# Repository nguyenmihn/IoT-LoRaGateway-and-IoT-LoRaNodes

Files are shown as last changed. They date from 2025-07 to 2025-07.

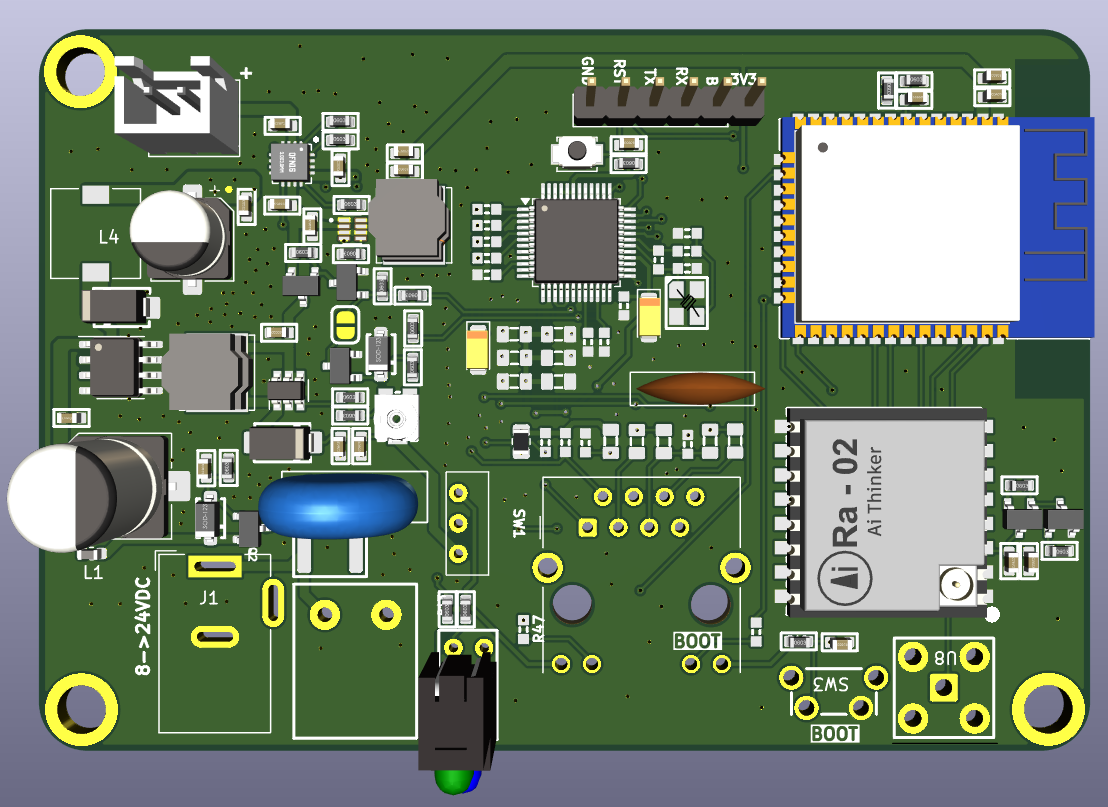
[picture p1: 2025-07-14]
gateway.png

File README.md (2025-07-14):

# IoT-LoRaGateway-and-IoT-LoRaNodes
Design and implementation of IoT-LoRaGateway and IoT-LoRaNodes applied in a building safety monitoring system (sponsored by ICE Meca Tech, Korea &amp; IoTVision)
# 🔥 Panel Safety Monitoring System (PSMS)

**PSMS** is an embedded IoT project integrating hardware design, firmware, and LoRa/TCP-IP communication to monitor and detect fire risks inside electrical panels.

---

## 📌 Project Overview

- **Goal**: Detect early signs of sparks, smoke, and temperature anomalies in panels.
- **Use cases**: Industrial installations like thermal power plants.
- **Communication**: LoRa for remote, low-power detection; TCP-IP as wired fallback.

---

## ⚙️ Features

- IR Spark + UV Spark sensors  
- IR Temperature sensor + 2-channel K-type thermocouples  
- Smoke sensor with high sensitivity  
- Real-time monitoring and alerting via embedded firmware  
- HMI interface for live data reading  
- LoRa range up to 2 km; Ethernet option  
- Battery backup to ensure operation during power failure

---

## 🧩 Hardware Components

- Custom PCB with sensor interfaces  
- MCU (e.g., STM32 or ESP32) running embedded C/C++ firmware  
- LoRa module (e.g., SX126x series) or Ethernet board  
- Enclosure designed for panel mounting

---

## 🗂 Repository Structure (Example)

├── hardware/ # PCB schematics, Gerbers, BOM

├── firmware/ # MCU code (C/C++), sensor drivers, LoRa/TCP‑IP stack

├── gateway/ # LoRa gateway or server-side interface code

└── README.md # This file

yaml
Sao chép
Chỉnh sửa

---

## 🚀 Quick Start

1. **Hardware setup**:  
   Assemble PCB, connect sensors, LoRa/Ethernet, and battery backup.

2. **Build firmware**:  
   ```bash
   cd firmware
   make all
hoặc dùng PlatformIO / STM32CubeIDE.

Configure LoRa:

Set frequency (433MHz)

Configure gateway addresses

Enable TCP-IP if used

Deploy HMI:
Copy firmware/ui files lên HMI panel.

Test & Calibrate:
Verify readings, range test LoRa, simulate spark/smoke.

✅ Deployed Example
Installed in Yeongheung Thermal Power Plant (Unit #5, 870 MW)

Runs under KOEN-supported R&D project (Dec 2022–Dec 2024)

🛠 Tech Stack
MCU: STM32/ESP32 with firmware in C/C++

Communication: LoRa (Semtech SX126x), TCP/IP Ethernet module

Sensors: IR/UV spark, temperature, thermocouple, smoke

Build tools: Makefile or PlatformIO / STM32CubeIDE

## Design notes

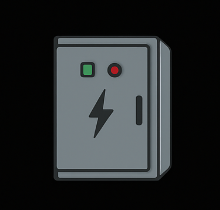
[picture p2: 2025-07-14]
firmware/web/tudien.png

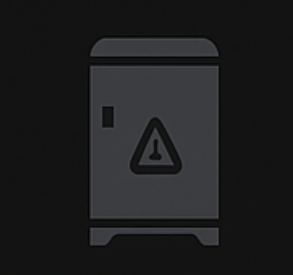
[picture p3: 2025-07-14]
firmware/web/screenshot_1748689128.png

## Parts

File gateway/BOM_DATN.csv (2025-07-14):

# | Reference | Value | Datasheet | Footprint | Qty | DNP
1 | BT1 | Battery_18650 | ~ | IVS_FOOTPRINTS:XH 2.54 2Pin Female | 1
2 | C1,C9,C10,C11,C12,C16,C18 | 10uF | ~ | IVS_FOOTPRINTS:C_0603 | 7 | https://www.thegioiic.com/tu-gom-0603-10uf-25v
3 | C2,C13,C17,C19,C23 | 100nF | ~ | IVS_FOOTPRINTS:C_0603 | 5 | https://www.thegioiic.com/tu-gom-0603-100nf-0-1uf-50v
4 | C3,C4,C6,C7,C8,C15,C21 | 1uF | ~ | IVS_FOOTPRINTS:C_0603 | 7 | https://www.thegioiic.com/tu-gom-0603-1uf-50v
5 | C5 | 220uF 35V | ~ | Capacitor_SMD:CP_Elec_8x10.5 | 1 | https://www.thegioiic.com/tu-nhom-smd-220uf-35v-8x10-5mm
6 | C14 | 110uF 10V | ~ | Capacitor_SMD:CP_Elec_6.3x5.4 | 1 | https://www.thegioiic.com/tu-nhom-smd-330uf-6-3v-6-3x7-7mm
7 | C29,C30 | 18p | ~ | IVS_FOOTPRINTS:C_0603 | 2 | https://www.thegioiic.com/tu-gom-0603-18pf-50v
8 | C31,C45,C46,C47,C48,C49,C50 | 0.1uF | ~ | -- mixed values -- | 7
9 | C33 | 1nF/2kV | ~ | Capacitor_THT:C_Disc_D10.0mm_W2.5mm_P5.00mm | 1
10 | C34 | 22nF | ~ | IVS_FOOTPRINTS:C_0603 | 1 | https://www.thegioiic.com/tu-gom-0603-22nf-50v
11 | C35,C38 | 6.8nF | ~ | IVS_FOOTPRINTS:C_0805 | 2 | https://www.thegioiic.com/tu-gom-0805-6-8nf-50v
12 | C39,C40 | 10nF | ~ | IVS_FOOTPRINTS:C_0603 | 2 | https://www.thegioiic.com/tu-gom-0603-10nf-50v
13 | C41 | 4.7uF | ~ | IVS_FOOTPRINTS:C_0603 | 1
14 | C51,C52 | 10 uF 16V | ~ | Capacitor_Tantalum_SMD:CP_EIA-3216-10_Kemet-I | 2
15 | D1 | LED_Dual_AKAK | ~ | IVS_FOOTPRINTS:LED_Housing_Dual | 1 | https://www.thegioiic.com/bo-chi-thi-2-led-xanh-la-do-3mm-de-nhua-han-pcb
16 | D2,D3 | SS34 |  | IVS_FOOTPRINTS:D_SMA | 2 | https://www.thegioiic.com/twgmc-ss34-sma-diode-schottky-3a
17 | F1 | 1A | ~ | IVS_FOOTPRINTS:F_1812 | 1 | https://www.thegioiic.com/mf-msmf020-2-cau-chi-tu-phuc-hoi-1812-0-20a-30v
18 | FB1 | FerriteBead | ~ | IVS_FOOTPRINTS:R_0805_2012Metric | 1
19 | H1 | MountingHole | ~ | minh_iot:MountingHole_3mm_M4_DIN965_Pad | 1
20 | J1 | Jack-DC | ~ | Connector_BarrelJack:BarrelJack_Wuerth_6941xx301002 | 1 | https://www.thegioiic.com/dc5521-dau-noi-nguon-dc-cai-5521-han-pcb-kim-2-1mm
21 | J2 | Screw_Terminal_01x02 | ~ | IVS_FOOTPRINTS:KF-5.08-2P | 1
22 | J3 | Conn_01x06_Male | ~ | Connector_PinHeader_2.54mm:PinHeader_1x06_P2.54mm_Vertical | 1
23 | J6 | RJ45_Hanrun_HR911105A_Horizontal | https://datasheet.lcsc.com/lcsc/1811141815_HANRUN-Zhongshan-HanRun-Elec-HR911105A_C12074.pdf | Connector_RJ:RJ45_Hanrun_HR911105A_Horizontal | 1
24 | JP1 | SolderJumper_2_Open | ~ | IVS_FOOTPRINTS:SolderJumper-2_P1.3mm_Open_RoundedPad1.0x1.5mm | 1
25 | L1 | VHF160808H2N2ST | ~ | Inductor_SMD:L_0603_1608Metric | 1 | https://www.thegioiic.com/vhf160808h2n2st-cuon-cam-2-2nh-0603-1a
26 | L2 | 22uH | ~ | Inductor_SMD:L_Bourns_SRN6045TA | 1 | https://www.thegioiic.com/cuon-cam-dan-smd-cd53-5852-220-22uh-1-5a
27 | L3 | 2.2uH | ~ | Inductor_SMD:L_Bourns_SRN6045TA | 1
28 | L4 | 47uH | ~ | IVS_FOOTPRINTS:L_7.3x7.3_H4.5 | 1 | https://www.thegioiic.com/cuon-cam-dan-smd-cdrh74-7345-470-47uh-1-03a
29 | Q1,Q3,Q5 | SI2300 | -- mixed values -- | IVS_FOOTPRINTS:SOT23-3 | 3 | https://www.thegioiic.com/si2300ds-mosfet-kenh-n-30v-3-6a-sot-23
30 | Q2,Q4,Q6 | SI2301 | -- mixed values -- | IVS_FOOTPRINTS:SOT23-3 | 3 | https://www.thegioiic.com/si2301ds-mosfet-kenh-p-20v-2-3a-sot-23-3
31 | R1,R6,R13,R14 | 1K | ~ | IVS_FOOTPRINTS:R_0603 | 4
32 | R2,R12,R17,R18 | 10K | ~ | IVS_FOOTPRINTS:R_0603 | 4
33 | R3 | 12k | ~ | IVS_FOOTPRINTS:R_0603 | 1
34 | R4 | 270K | ~ | IVS_FOOTPRINTS:R_0603 | 1
35 | R5,R9 | 1K2 | ~ | IVS_FOOTPRINTS:R_0603 | 2
36 | R7,R11,R23,RV2 | 100K | ~ | -- mixed values -- | 4
37 | R8,R15,R24 | 20K | ~ | IVS_FOOTPRINTS:R_0603 | 3
38 | R10 | 220K | ~ | IVS_FOOTPRINTS:R_0603 | 1
39 | R16 | 2K7 | ~ | IVS_FOOTPRINTS:R_0603 | 1
40 | R36 | 1M | ~ | IVS_FOOTPRINTS:R_0603 | 1
41 | R37,R38,R45,R52,R53 | 0R | ~ | IVS_FOOTPRINTS:R_0603 | 5
42 | R46,R47 | 330R | ~ | IVS_FOOTPRINTS:R_0603 | 2
43 | R48,R50 | 49R9 | ~ | IVS_FOOTPRINTS:R_0603 | 2
44 | R51 | 10R | ~ | IVS_FOOTPRINTS:R_0805 | 1
45 | R54,R55 | 82R 1% | ~ | IVS_FOOTPRINTS:R_0805 | 2
46 | R56 | 12.4k | ~ | IVS_FOOTPRINTS:R_0603 | 1
47 | RV1 | 07D330K | ~ | Varistor:RV_Disc_D12mm_W4.2mm_P7.5mm | 1 | https://www.thegioiic.com/tu-chong-set-varistor-07d330k-33v
48 | SW1 | MSK-38/SS-12D00 | https://www.nidec-components.com/e/catalog/switch/cas.pdf | IVS_FOOTPRINTS:SW_MSK-38 | 1
49 | SW2,SW3 | SW_Push | ~ | -- mixed values -- | 2
50 | TP1 | TestPoint | ~ | IVS_FOOTPRINTS:TestPoint_Pad_D1.0mm | 1
51 | U1 | TPS62840DLCR |  | IVS_FOOTPRINTS:VSON-HR - 1 mm | 1
52 | U2 | BQ24075RGT | http://www.ti.com/lit/ds/symlink/bq24075.pdf | IVS_FOOTPRINTS:VQFN-16-1EP_3x3mm_P0.5mm_EP1.6x1.6mm_ThermalVias | 1
53 | U3 | MT3608 | https://www.olimex.com/Products/Breadboarding/BB-PWR-3608/resources/MT3608.pdf | IVS_FOOTPRINTS:SOT-23-6 | 1 | https://www.thegioiic.com/mt3608-ic-dieu-chinh-tang-ap-2a-sot-23-6
54 | U4 | XL1509 | https://datasheet.lcsc.com/lcsc/1809050422_XLSEMI-XL1509-5-0E1_C61063.pdf | IVS_FOOTPRINTS:SOIC-8_3.9x4.9mm_P1.27mm | 1 | https://www.thegioiic.com/xl1509-5-0e1-ic-on-ap-5v-2a-8-soic
55 | U5 | ESP32-WROOM-32UE | https://www.espressif.com/sites/default/files/documentation/esp32-wroom-32d_esp32-wroom-32u_datasheet_en.pdf | IVS_FOOTPRINTS:ESP32-WROOM-32E | 1 | https://www.thegioiic.com/esp32-wroom-32e-n4-module-wifi-bluetooth-4mb-flash-2-4ghz
56 | U7 | Ai-Thinker-Ra-02 | http://wiki.ai-thinker.com/_media/lora/docs/c048ps01a1_ra-02_product_specification_v1.1.pdf | IVS_FOOTPRINTS:MODULE_RA-02_LORA | 1 | https://www.thegioiic.com/sx1278-lora-ra-02-ai-thinker-mach-thu-phat-rf-433mhz-10km
57 | U8 | Ipex | https://datasheet.lcsc.com/lcsc/1811091710_HRS-Hirose-U-FL-R-SMT-1-80_C88374.pdf | IVS_FOOTPRINTS:Connector_Coaxial_SMA | 1 | https://www.thegioiic.com/ahcg-204-cong-rf-ipex-g1-2-chan-dan-smd
58 | U12 | W5500 | http://wizwiki.net/wiki/lib/exe/fetch.php/products:w5500:w5500_ds_v109e.pdf | Package_QFP:LQFP-48_7x7mm_P0.5mm | 1
59 | Y1 | Crystal_MCU | https://docs.rs-online.com/ec34/0900766b816028ea.pdf | IVS_FOOTPRINTS:Crystal_3225_4P_3.2x2.6mm | 1
60 | Z1 | 3V3 |  | IVS_FOOTPRINTS:D_SOD-123 | 1 | https://www.thegioiic.com/bzt52c5v1-diode-zener-5-1v-500mw
61 | Z2 | 12V |  | IVS_FOOTPRINTS:D_SOD-123 | 1

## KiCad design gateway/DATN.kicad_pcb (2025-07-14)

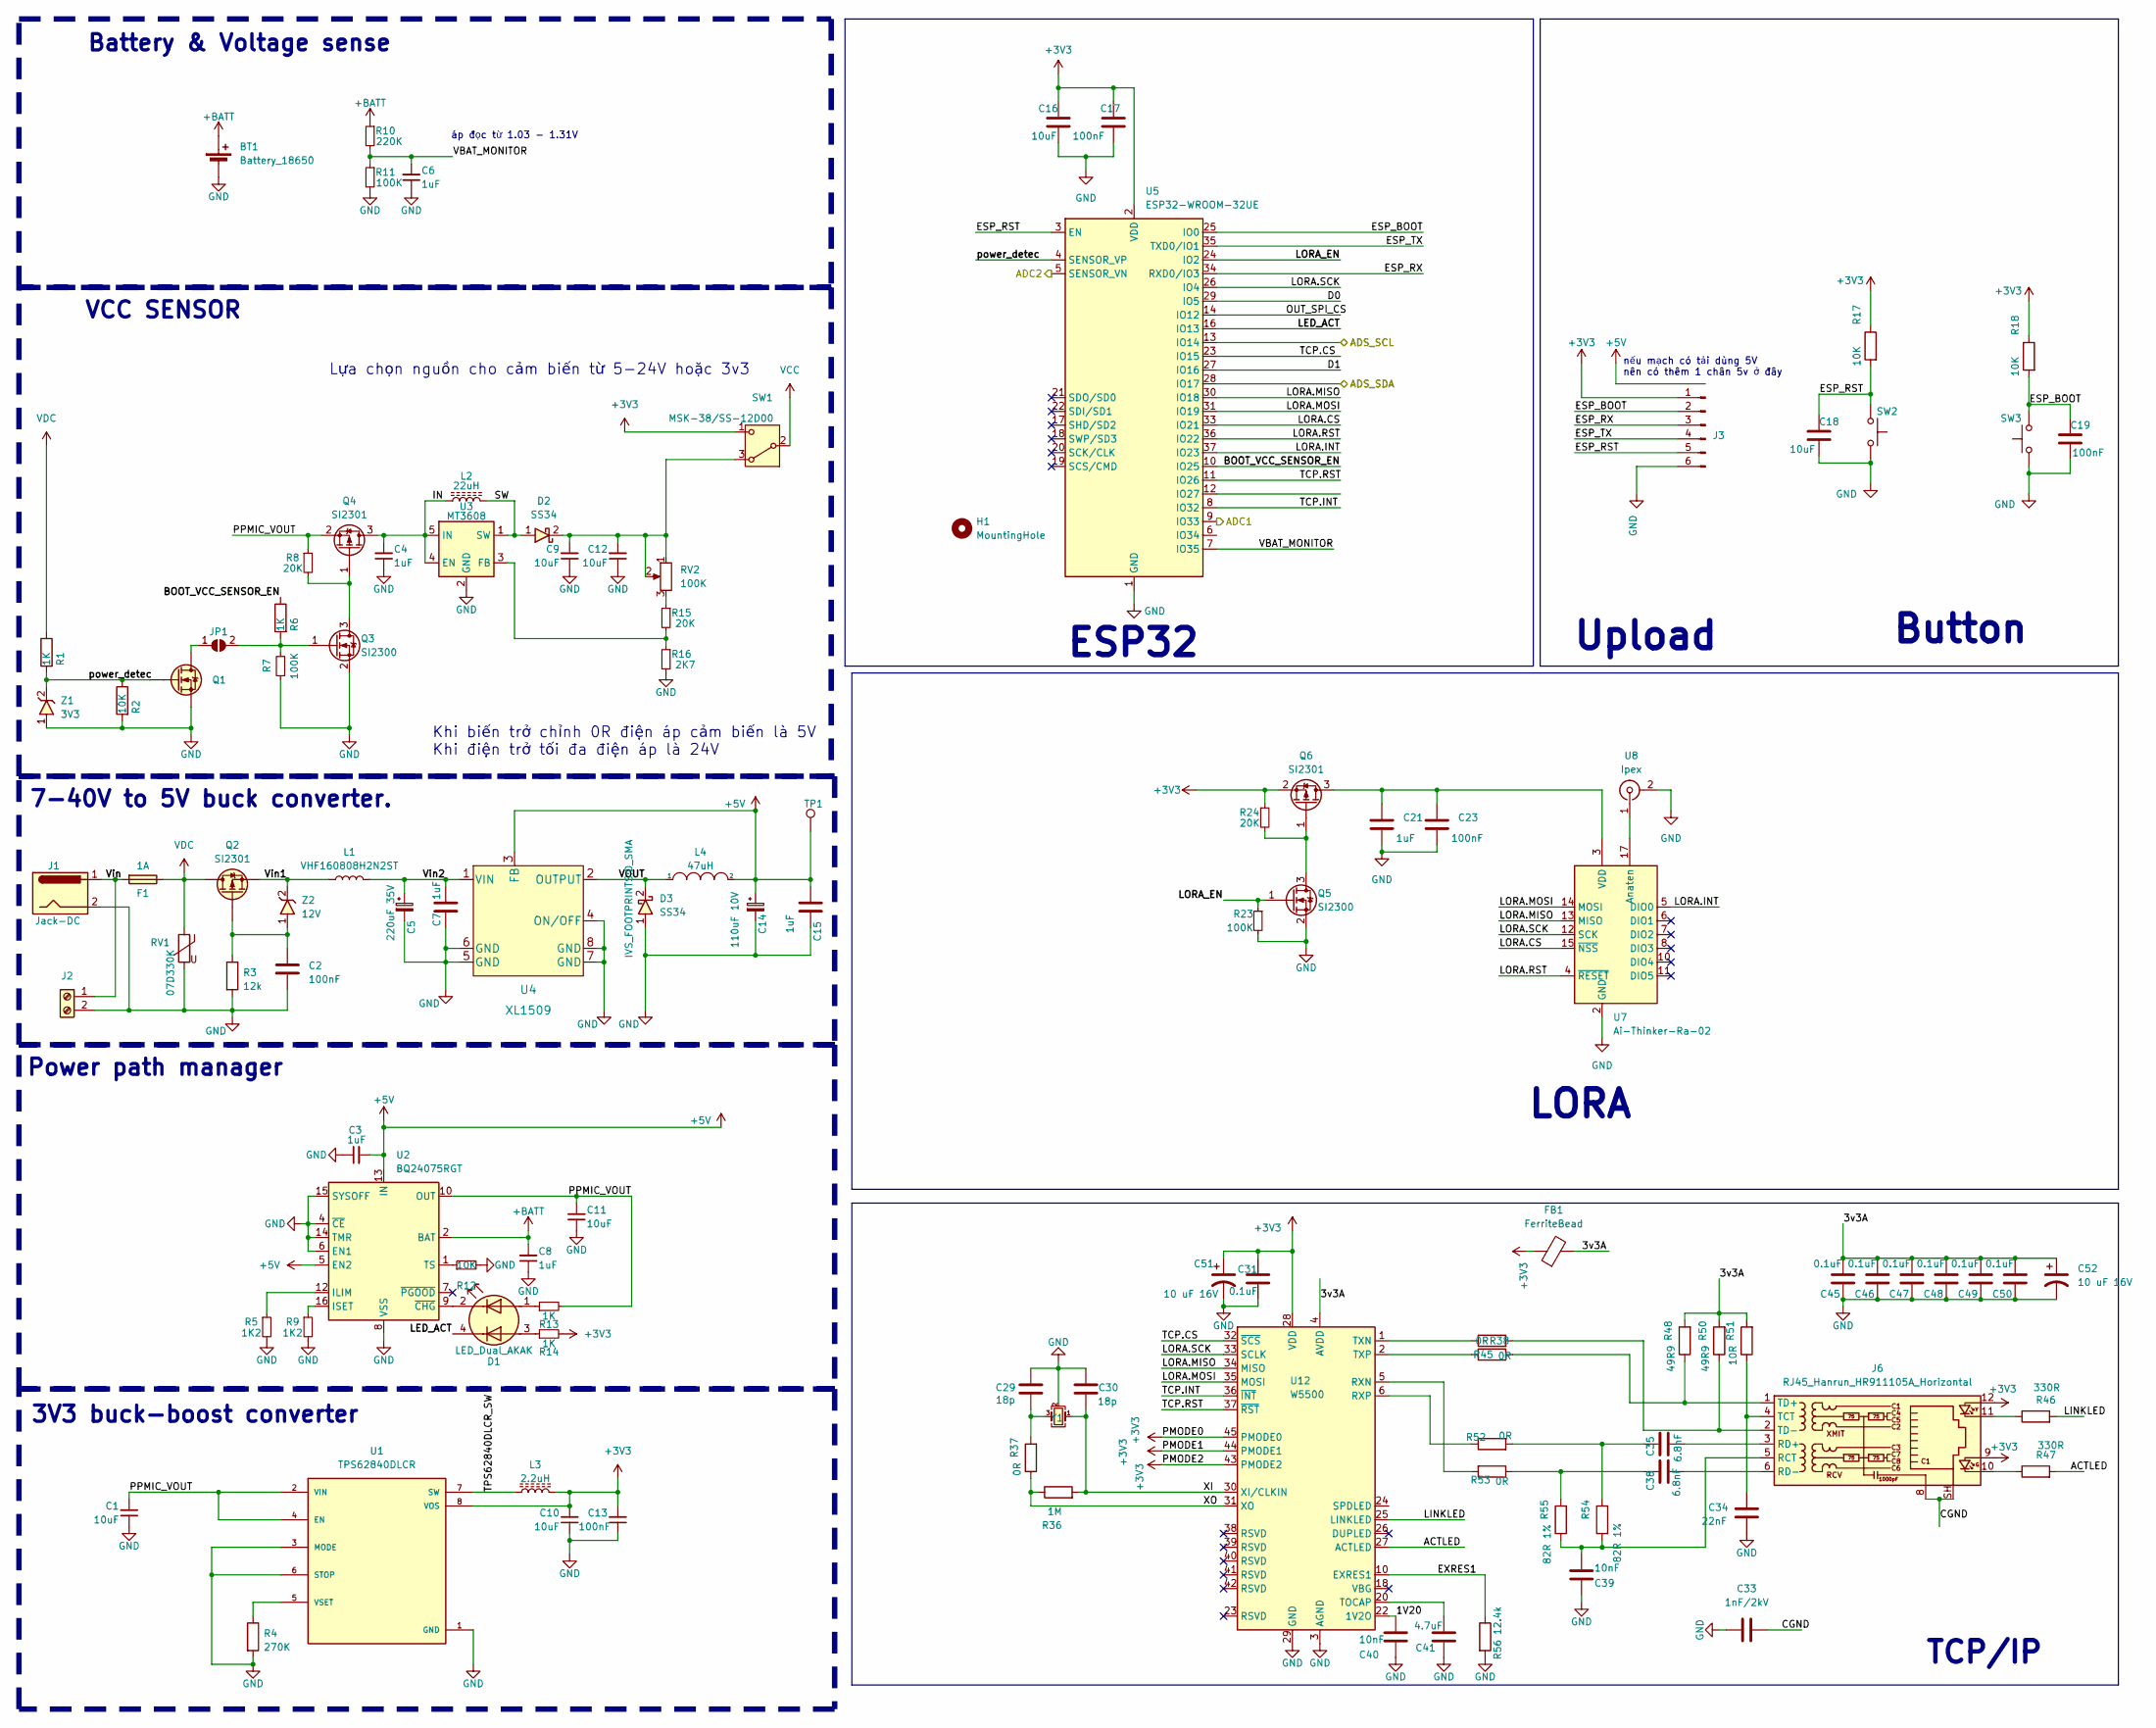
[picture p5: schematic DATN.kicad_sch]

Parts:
BT1: Battery_18650; XH 2.54 2Pin Female
C1, C9, C10, C11, C12, C16, C18: 10uF; C_0603
C2, C13, C17, C19, C23: 100nF; C_0603
C3, C4, C6, C7, C8, C15, C21: 1uF; C_0603
C5: 220uF 35V; CP_Elec_8x10.5
C14: 110uF 10V; CP_Elec_6.3x5.4
C29, C30: 18p; C_0603
C31: 0.1uF; C_0603
C33: 1nF/2kV; C_Disc_D10.0mm_W2.5mm_P5.00mm
C34: 22nF; C_0603
C35, C38: 6.8nF; C_0805
C39, C40: 10nF; C_0603
C41: 4.7uF; C_0603
C45, C46, C47, C48, C49, C50: 0.1uF; C_0805
C51, C52: 10 uF 16V; CP_EIA-3216-10_Kemet-I
D1: LED_Dual_AKAK; LED_Housing_Dual
D2, D3: SS34; D_SMA
F1: 1A; F_1812
FB1: FerriteBead; R_0805_2012Metric
H1: MountingHole; MountingHole_3mm_M4_DIN965_Pad
J1: Jack-DC; BarrelJack_Wuerth_6941xx301002
J2: Screw_Terminal_01x02; KF-5.08-2P
J3: Conn_01x06_Male; PinHeader_1x06_P2.54mm_Vertical
J6: RJ45_Hanrun_HR911105A_Horizontal
JP1: SolderJumper_2_Open; SolderJumper-2_P1.3mm_Open_RoundedPad1.0x1.5mm
L1: VHF160808H2N2ST; L_0603_1608Metric
L2: 22uH; L_Bourns_SRN6045TA
L3: 2.2uH; L_Bourns_SRN6045TA
L4: 47uH; L_7.3x7.3_H4.5
Q1, Q3, Q5: SI2300; SOT23-3
Q2, Q4, Q6: SI2301; SOT23-3
R1, R6, R13, R14: 1K; R_0603
R2, R12, R17, R18: 10K; R_0603
R3: 12k; R_0603
R4: 270K; R_0603
R5, R9: 1K2; R_0603
R7, R11, R23: 100K; R_0603
R8, R15, R24: 20K; R_0603
R10: 220K; R_0603
R16: 2K7; R_0603
R36: 1M; R_0603
R37, R38, R45, R52, R53: 0R; R_0603
R46, R47: 330R; R_0603
R48, R50: 49R9; R_0603
R51: 10R; R_0805
R54, R55: 82R 1%; R_0805
R56: 12.4k; R_0603
RV1: 07D330K; RV_Disc_D12mm_W4.2mm_P7.5mm
RV2: 100K; Potentiometer_Bourns_TC33X_Vertical
SW1: MSK-38/SS-12D00; SW_MSK-38
SW2: SW_Push; SW_SPST_B3U-1000P
SW3: SW_Push; SW_6x6_90DEG
TP1: TestPoint; TestPoint_Pad_D1.0mm
U1: TPS62840DLCR; VSON-HR - 1 mm
U2: BQ24075RGT; VQFN-16-1EP_3x3mm_P0.5mm_EP1.6x1.6mm_ThermalVias
U3: MT3608; SOT-23-6
U4: XL1509; SOIC-8_3.9x4.9mm_P1.27mm
U5: ESP32-WROOM-32UE; ESP32-WROOM-32E
U7: Ai-Thinker-Ra-02; MODULE_RA-02_LORA
U8: Ipex; Connector_Coaxial_SMA
U12: W5500; LQFP-48_7x7mm_P0.5mm
Y1: Crystal_MCU; Crystal_3225_4P_3.2x2.6mm
Z1: 3V3; D_SOD-123
Z2: 12V; D_SOD-123

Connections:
+3V3: C10.2, C13.2, C16.1, C17.1, C31.1, C51.1, FB1.1, J3.1, J6.9, J6.12, L3.2, Q6.2 (S), R14.2, R17.1, R18.1, R24.1, SW1.1 (C), U1.8 (VOS), U5.2 (VDD), U12.28 (VDD), U12.43 (PMODE2), U12.44 (PMODE1), U12.45 (PMODE0)
+5V: C3.2, C14.1, C15.2, L4.2, TP1.1, U2.5 (EN2), U2.13 (IN), U4.3 (FB)
+BATT: BT1.1 (+), C8.2, R10.1, U2.2 (BAT), U2.3 (BAT)
/1V20: C40.2, U12.22 (1V2O)
/3v3A: C45.2, C46.2, C47.2, C48.2, C49.2, C50.2, C52.1, FB1.2, R48.2, R50.2, R51.2, U12.4 (AVDD), U12.8 (AVDD), U12.11 (AVDD), U12.15 (AVDD), U12.17 (AVDD), U12.21 (AVDD)
/ACTLED: R47.2, U12.27 (ACTLED)
/ADC1: U5.9 (IO33)
/ADC2: U5.5 (SENSOR_VN)
/ADS_SCL: U5.13 (IO14)
/ADS_SDA: U5.28 (IO17)
/BOOT_VCC_SENSOR_EN: R6.1, U5.10 (IO25)
/CGND: C33.2, J6.8, J6.SH
/D0: U5.29 (IO5)
/D1: U5.27 (IO16)
/ESP_BOOT: C19.1, J3.2, R18.2, SW3.2, U5.25 (IO0)
/ESP_RST: C18.1, J3.5, R17.2, SW2.2, U5.3 (EN)
/ESP_RX: J3.3, U5.34 (RXD0/IO3)
/ESP_TX: J3.4, U5.35 (TXD0/IO1)
/EXRES1: R56.1, U12.10 (EXRES1)
/IN: C4.2, L2.1, Q4.3 (D), U3.4 (EN), U3.5 (IN)
/LED_ACT: D1.4 (K2), U5.16 (IO13)
/LINKLED: R46.2, U12.25 (LINKLED)
/LORA.CS: U5.33 (IO21), U7.15 (~NSS)
/LORA.INT: U5.37 (IO23), U7.5 (DIO0)
/LORA.MISO: U5.30 (IO18), U7.13 (MISO), U12.34 (MISO)
/LORA.MOSI: U5.31 (IO19), U7.14 (MOSI), U12.35 (MOSI)
/LORA.RST: U5.36 (IO22), U7.4 (~RESET)
/LORA.SCK: U5.26 (IO4), U7.12 (SCK), U12.33 (SCLK)
/LORA_EN: Q5.1 (G), R23.1, U5.24 (IO2)
/OUT_SPI_CS: U5.14 (IO12)
/PPMIC_VOUT: C1.2, C11.2, Q4.2 (S), R8.1, R13.2, U1.2 (VIN), U1.4 (EN), U2.10 (OUT), U2.11 (OUT)
/SW: D2.1, L2.2, U3.1 (SW)
/TCP.CS: U5.23 (IO15), U12.32 (~SCS)
/TCP.INT: U5.8 (IO32), U12.36 (~INT)
/TCP.RST: U5.11 (IO26), U12.37 (~RST)
/TPS62840DLCR_SW: L3.1, U1.7 (SW)
/VBAT_MONITOR: C6.2, R10.2, R11.1, U5.7 (IO35)
/VOUT: D3.2, L4.1, U4.2 (OUTPUT)
/Vin: F1.1, J1.1, J2.1
/Vin1: L1.1, Q2.2 (S), Z2.2
/Vin2: C5.1, C7.2, L1.2, U4.1 (VIN)
/XI: C30.2, R36.2, U12.30 (XI/CLKIN), Y1.1
/XO: R36.1, R37.1, U12.31 (XO)
/power_detec: Q1.1 (G), R1.2, R2.1, U5.4 (SENSOR_VP), Z1.2
GND: BT1.2 (-), C1.1, C2.2, C3.1, C4.1, C5.2, C6.1, C7.1, C8.1, C9.1, C10.1, C11.1, C12.1, C13.1, C14.2, C15.1, C16.2, C17.2, C18.2, C19.2, C21.2, C23.2, C29.1, C30.1, C31.2, C33.1, C34.2, C39.1, C40.1, C41.1, C45.1, C46.1, C47.1, C48.1, C49.1, C50.1, C51.2, C52.2, D3.1, J1.2, J2.2, J3.6, Q1.2 (S), Q3.2 (S), Q5.2 (S), R2.2, R3.2, R4.2, R5.2, R7.2, R9.2, R11.2, R12.2, R16.2, R23.2, R56.2, RV1.2, SW2.1, SW3.1, U1.1 (GND), U1.3 (MODE), U1.6 (STOP), U2.4 (~CE), U2.6 (EN1), U2.8 (VSS), U2.14 (TMR), U2.15 (SYSOFF), U2.17 (VSS), U3.2 (GND), U4.4 (ON/OFF), U4.5 (GND), U4.6 (GND), U4.7 (GND), U4.8 (GND), U5.1 (GND), U5.15 (GND), U5.38 (GND), U5.39 (GND), U7.1 (GND), U7.2 (GND), U7.9 (GND), U7.16 (GND), U8.2, U12.3 (AGND), U12.9 (AGND), U12.14 (AGND), U12.16 (AGND), U12.19 (AGND), U12.29 (GND), U12.48 (AGND), Y1.2, Y1.4, Z1.1
unnamed: C29.2, R37.2, Y1.3
unnamed: C35.1, R52.2, R54.2
unnamed: C38.1, R53.1, R55.2
unnamed: D1.1 (A1), R13.1
unnamed: D1.3 (A2), R14.1
unnamed: D1.2 (K1), U2.9 (~CHG)
unnamed: J6.10, R47.1
unnamed: J6.11, R46.1
unnamed: C39.2, J6.5 (RCT), R54.1, R55.1
unnamed: C35.2, J6.3 (RD+)
unnamed: C38.2, J6.6 (RD-)
unnamed: C34.1, J6.4 (TCT), R51.1
unnamed: J6.1 (TD+), R45.1, R48.1
unnamed: J6.2 (TD-), R38.2, R50.1
unnamed: JP1.1 (A), Q1.3 (D)
unnamed: JP1.2 (B), Q3.1 (G), R6.2, R7.1
unnamed: C2.1, Q2.1 (G), R3.1, Z2.1
unnamed: Q3.3 (D), Q4.1 (G), R8.2
unnamed: Q5.3 (D), Q6.1 (G), R24.2
unnamed: C21.1, C23.1, Q6.3 (D), U7.3 (VDD)
unnamed: R15.1, RV2.3
unnamed: C9.2, C12.2, D2.2, RV2.1, RV2.2, SW1.3 (A)
unnamed: R4.1, U1.5 (VSET)
unnamed: R5.1, U2.12 (ILIM)
unnamed: R9.1, U2.16 (ISET)
unnamed: R12.1, U2.1 (TS)
unnamed: R15.2, R16.1, U3.3 (FB)
unnamed: U7.17 (Anaten), U8.1
unnamed: R53.2, U12.5 (RXN)
unnamed: R52.1, U12.6 (RXP)
unnamed: C41.2, U12.20 (TOCAP)
unnamed: R38.1, U12.1 (TXN)
unnamed: R45.2, U12.2 (TXP)
VCC: SW1.2 (B)
VDC: F1.2, Q2.3 (D), R1.1, RV1.1

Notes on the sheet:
VCC SENSOR
LORA
Lựa chọn nguồn cho cảm biến từ 5-24V hoặc 3v3
3V3 buck-boost converter
Khi biến trở chỉnh 0R điện áp cảm biến là 5V Khi điện trở tối đa điện áp là 24V
nếu mạch có tải dùng 5V nên có thêm 1 chân 5v ở đây
áp đọc từ 1.03 - 1.31V
Button
Upload
Power path manager
ESP32
TCP/IP
7-40V to 5V buck converter.
Battery & Voltage sense

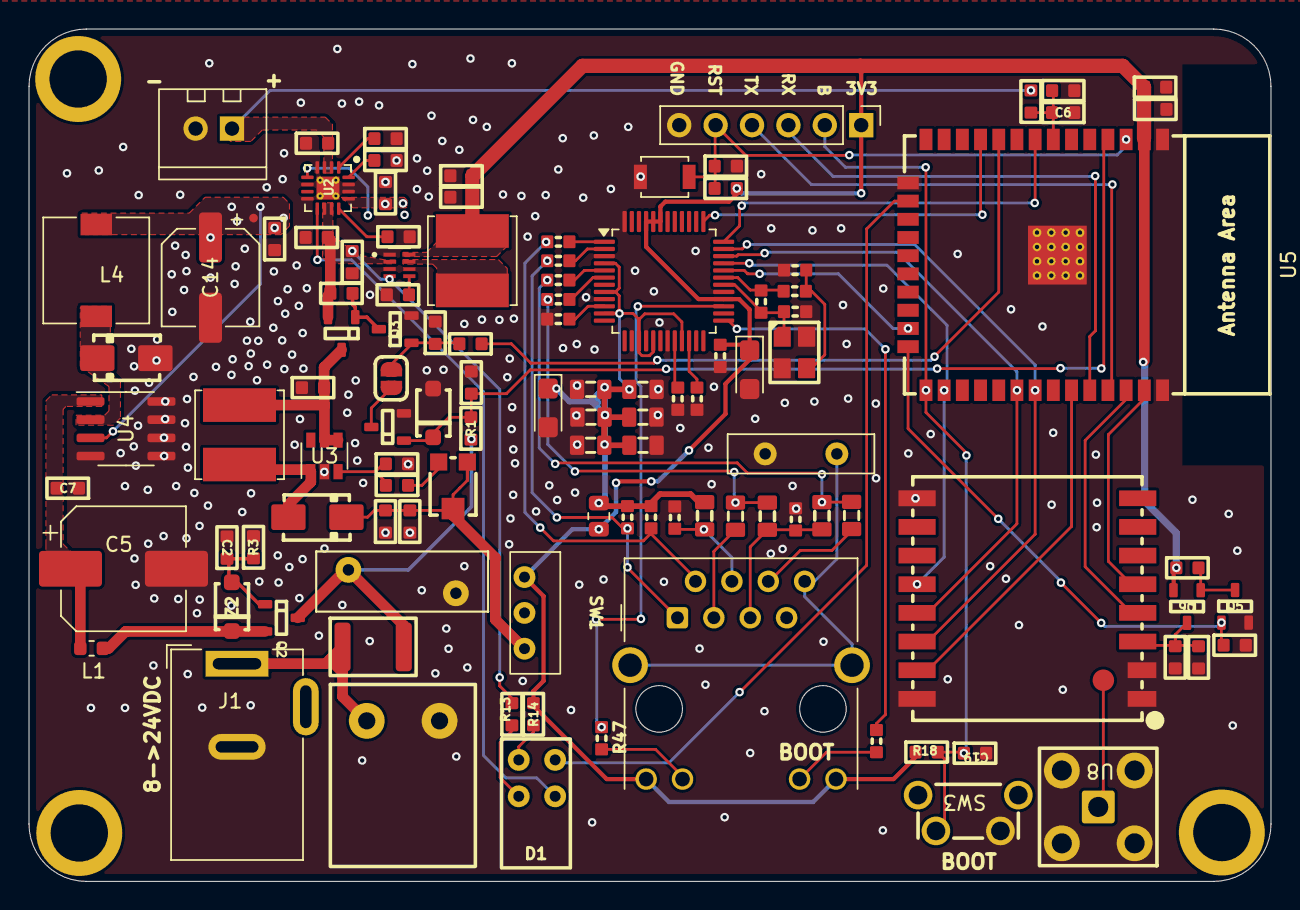
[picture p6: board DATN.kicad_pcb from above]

Board: 2 copper layers, 86.7 x 59.5 mm, 112 parts (1 on the bottom side), 72 nets.

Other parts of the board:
Designed by Nguyễn Đình Nhật Minh: LOGO; IoTVision_NewLoGo_30.9x8

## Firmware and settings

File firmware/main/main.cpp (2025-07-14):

#include "freertos/projdefs.h"
#include "main.h"
#include "adc_reader.h"
#include "lora.h"
#include <LoRa.h>

#include <Arduino.h>
#include "MLX90614.h"
#include "MaxRead6675.h"
#include "globals.h"

TaskHandle_t taskAdcHandle;
TaskHandle_t taskLoraHandle;
TaskHandle_t taskMLXHandle;
TaskHandle_t taskMax6675Handle;

void taskAdc(void *pvParameters) {
  while(1){
    readAdcValue();
    vTaskDelay(pdMS_TO_TICKS(500));
  }
}

void taskLora(void* pvParameters) {
  while (1) {
    sendLoRaPacket();
    vTaskDelay(pdMS_TO_TICKS(500)); // gửi mỗi 2 giây
  }
}

void taskMLX(void *pvParameters){
  while(1){
    ReadMLX96014();
    vTaskDelay(pdMS_TO_TICKS(500));
  }
}

void taskMax6675(void* pvParameters) {
  while (1) {
    ReadMax6675();
    vTaskDelay(pdMS_TO_TICKS(500)); // đọc mỗi 3 giây
  }
}
void SetupSystem(){
  spiMutex = xSemaphoreCreateMutex();
  initMax6675();
  initADC();
  initLoRa();
  initMLX90614();
  delay(100);
  xTaskCreatePinnedToCore(taskAdc, "ADC Task", 2048, NULL, 1, &taskAdcHandle, 1);
  xTaskCreatePinnedToCore(taskMax6675, "Max6675 Task", 4096, NULL, 1, &taskMax6675Handle, 1);
  xTaskCreatePinnedToCore(taskLora, "LoRa Task", 4096, NULL, 1, &taskLoraHandle, 0);
  xTaskCreatePinnedToCore(taskMLX, "MLX96014 Task", 4096, NULL, 1, &taskMLXHandle, 0);
  
}

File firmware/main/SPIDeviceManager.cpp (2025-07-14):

#include <Arduino.h>

// Định nghĩa rõ tên từng thiết bị
#define SPI_NONE  -1
#define SPI_LORA   0
#define SPI_ETH    1
#define SPI_MAX    2

#define CS_LORA    21
#define CS_ETH     15
#define CS_MAX     12

void selectSPIDevice(int device) {
  // Tắt tất cả thiết bị trước
  digitalWrite(CS_LORA, HIGH);
  digitalWrite(CS_ETH, HIGH);
  digitalWrite(CS_MAX, HIGH);

  // Bật đúng thiết bị được chọn
  switch (device) {
    case SPI_LORA: digitalWrite(CS_LORA, LOW); break;
    case SPI_ETH:  digitalWrite(CS_ETH, LOW);  break;
    case SPI_MAX:  digitalWrite(CS_MAX, LOW);  break;
    default: break; // SPI_NONE hoặc sai mã → không chọn gì
  }
}

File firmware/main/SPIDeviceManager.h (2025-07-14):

#ifndef SPI_DEVICE_MANAGER_H
#define SPI_DEVICE_MANAGER_H

#pragma once
#include <Arduino.h>

// Định nghĩa ID thiết bị SPI
#define SPI_NONE  -1
#define SPI_LORA   0
#define SPI_ETH    1
#define SPI_MAX    2

// Định nghĩa các chân CS tương ứng
#define CS_LORA    21
#define CS_ETH     15
#define CS_MAX     12

// Hàm điều khiển thiết bị SPI
void selectSPIDevice(int device);

#endif
